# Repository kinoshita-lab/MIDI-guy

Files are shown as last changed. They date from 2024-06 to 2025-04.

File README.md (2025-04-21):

# MIDI Guy by Kinoshita Laboratory

[japanese version](./README.ja.md)

MIDI Guy is a sound module with SAM2695, a single chip General MIDI(GM) synthesizer.
It can generate GM's 127 sound programs such as "Acoustic Grand Piano", "Trumpet", etc.

You can also use effects and EQs. Please refer to the SAM2695's datasheet for details.
<https://www.dream.fr/pdf/Serie2000/SAM_Datasheets/SAM2695.pdf>

# Selling PCBA at tindie.com!
Please visit: <https://www.tindie.com/products/kinoshitalab/midi-guy-rev-21-kit/>

## What's new for Revision 2.1

- USB Power input is replaced from micro USB to USB Type-C
- PCB Dimension modification: fit for Frisk case
- Support both TRS MIDI type A and B
- Add UART In terminal for the convinience using with microcontroller

## Kit contents

- Pre-assembled circuit board
- 2 pcs. of 3.5mm TRS Jack
- 1 pc. of DIN <-> TRS(Type A) Conversion Cable

## What you will need

- USB C Cable
- Power source for USB, such as power adapter or PC
- MIDI cable
- MIDI Output Device e.g. MIDI Keyboard, PC with MIDI Interface

## How to assemble

Solder the included TRS Jacks to the places shown below.

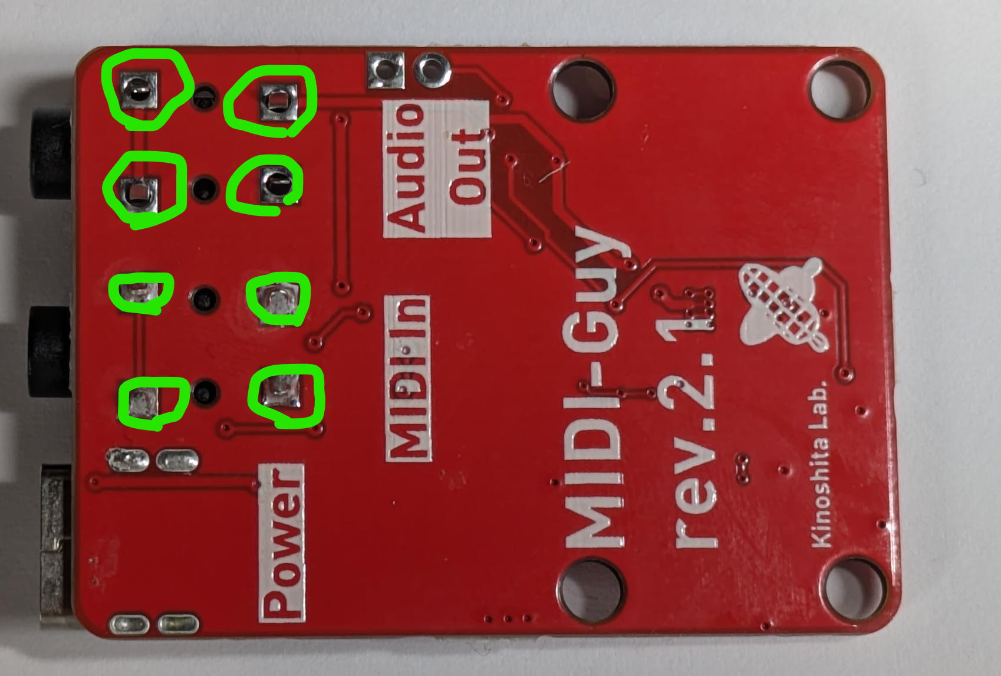
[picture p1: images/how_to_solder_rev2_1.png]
how to solder
  

## Usage

- Power: Connect the power source from USB
- MIDI In: Connect a MIDI message source(e.g. MIDI Keyboard, MIDI Interface connected to a PC)
- Audio Out: Outputs stereo sound, you can connect headphones directly.

## Schematics, design data, questions

<https://github.com/kinoshita-lab/MIDI-guy>

## Case Design
STL file made by @maks. Thank you!!
https://www.printables.com/model/1151667-case-for-a-midi-guy-pcb

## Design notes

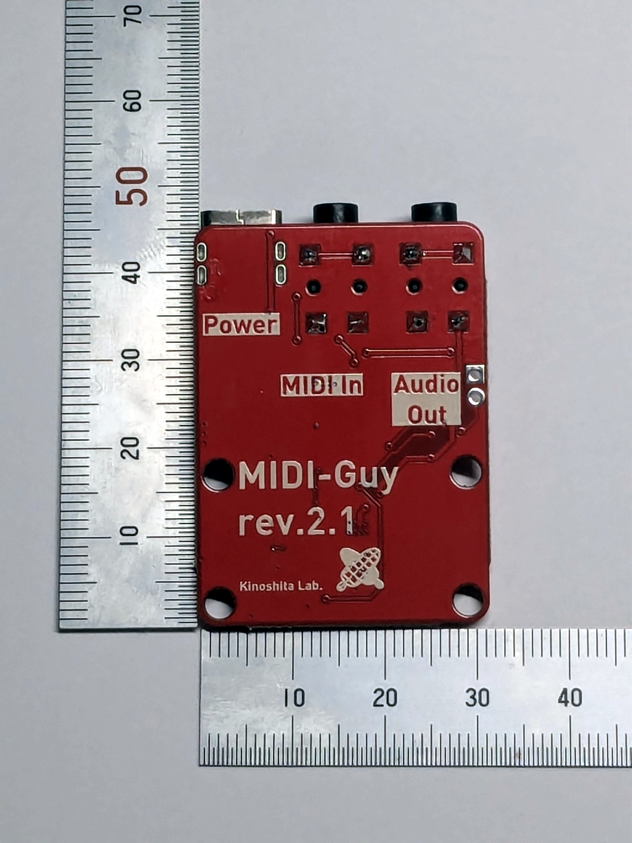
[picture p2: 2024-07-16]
pic_bottom.jpg

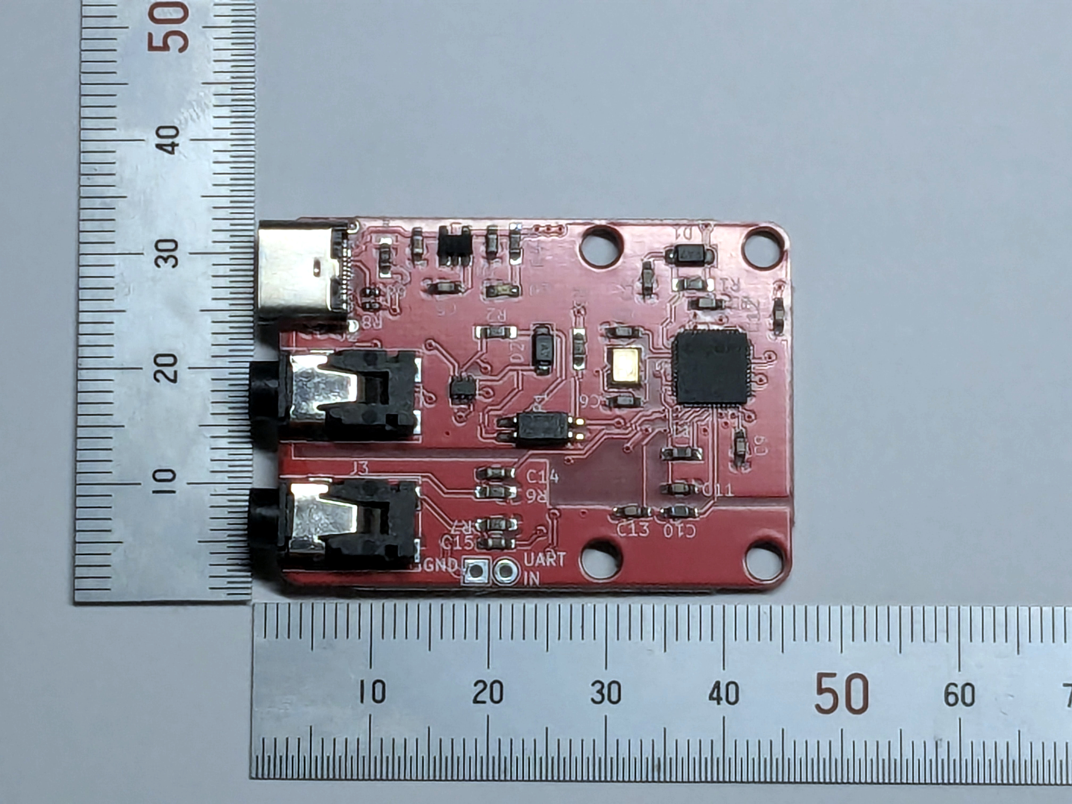
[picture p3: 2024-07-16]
pic_top.jpg

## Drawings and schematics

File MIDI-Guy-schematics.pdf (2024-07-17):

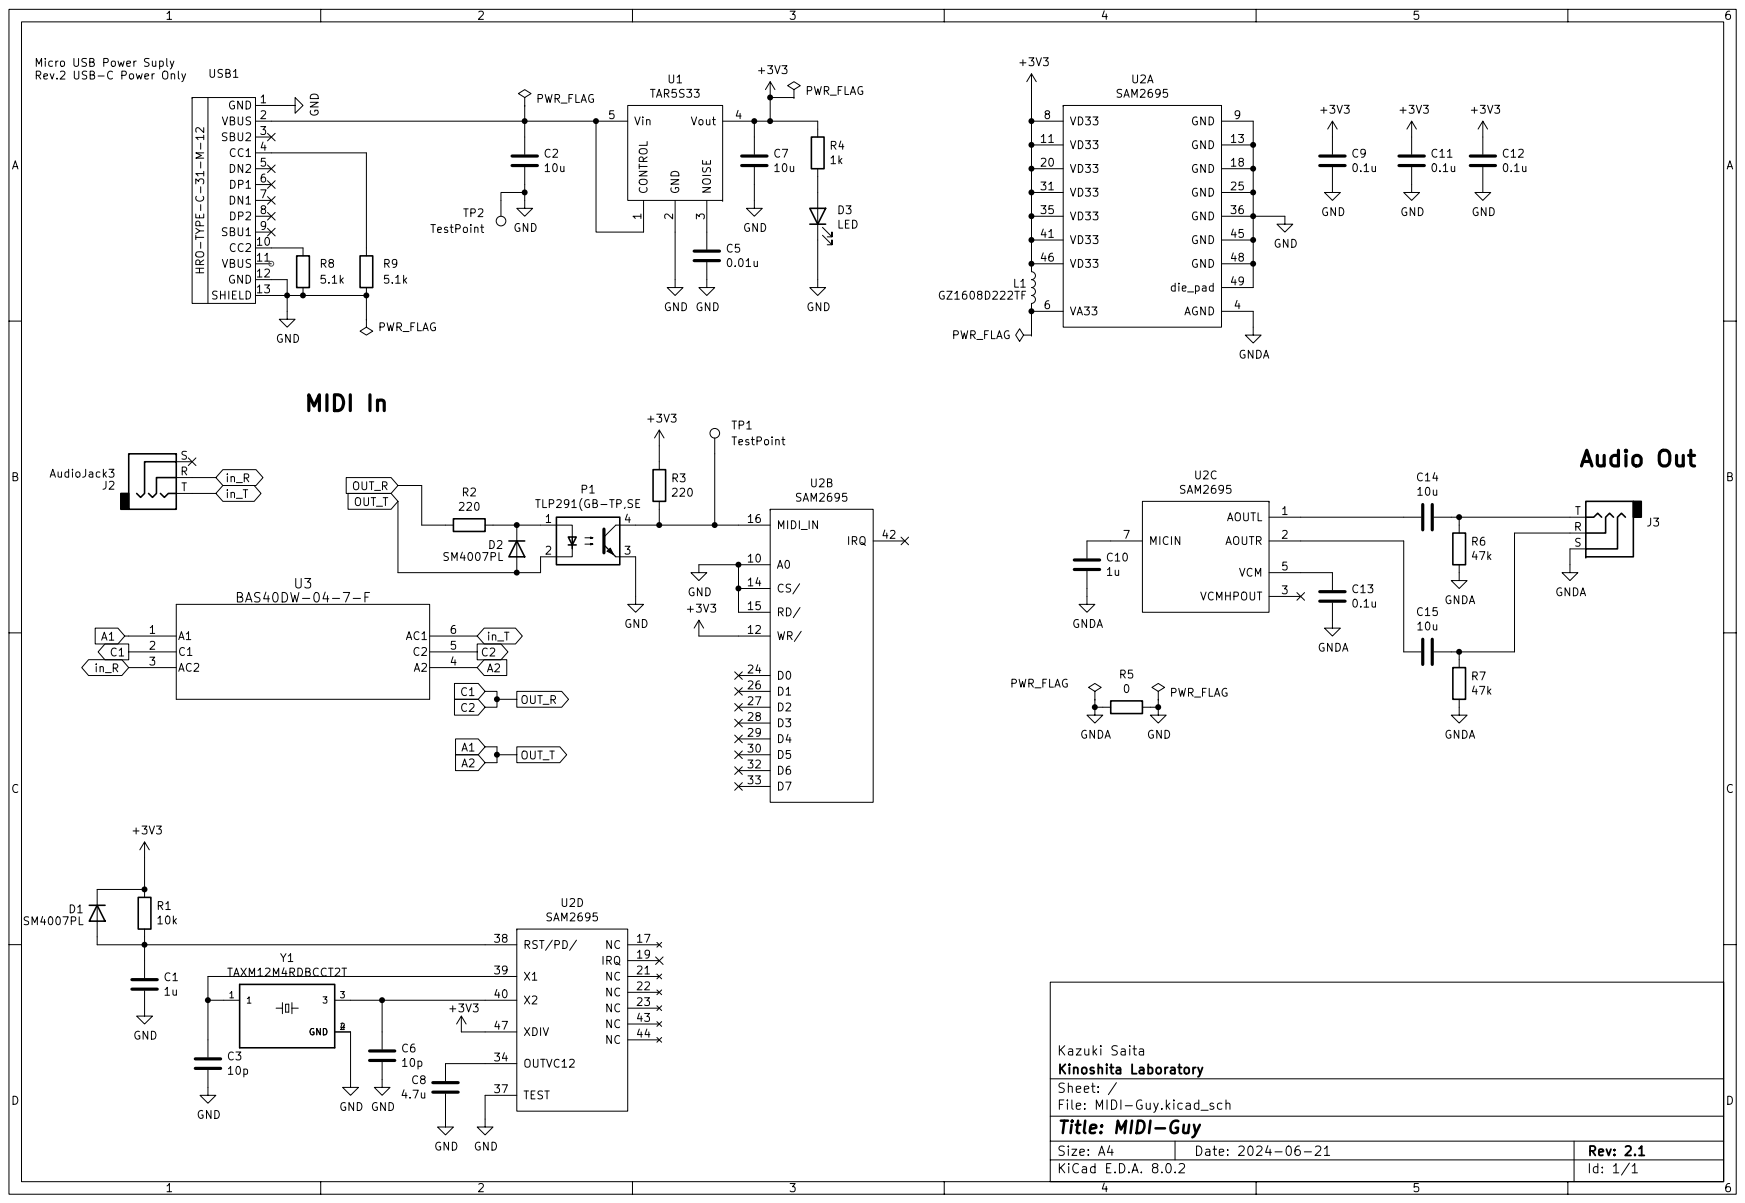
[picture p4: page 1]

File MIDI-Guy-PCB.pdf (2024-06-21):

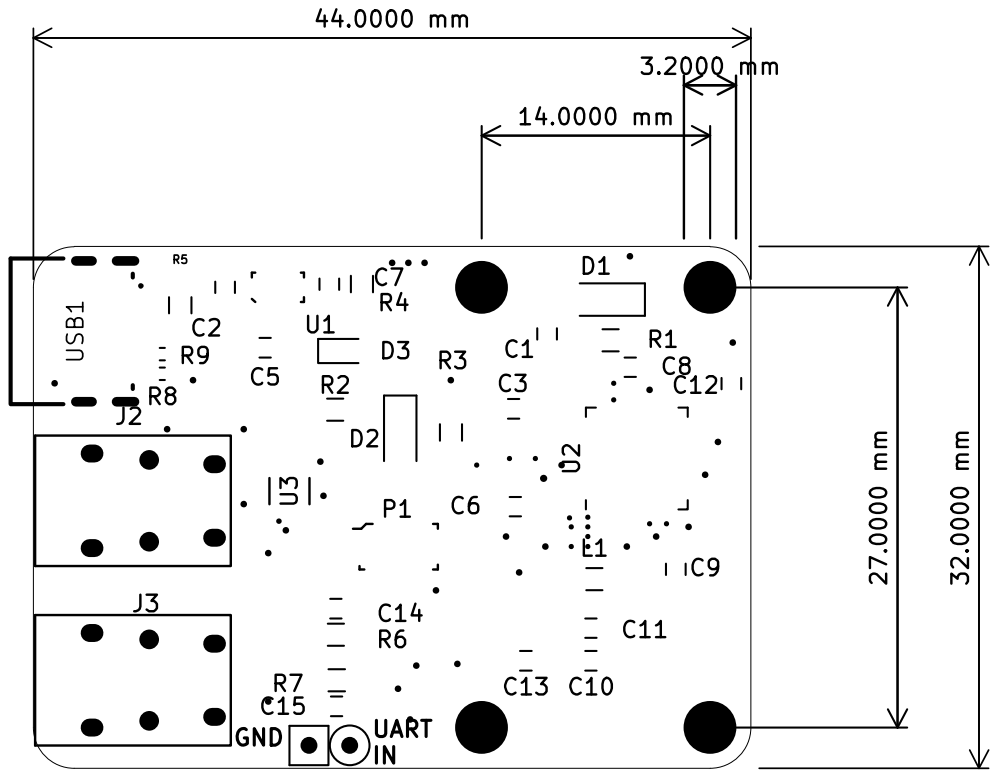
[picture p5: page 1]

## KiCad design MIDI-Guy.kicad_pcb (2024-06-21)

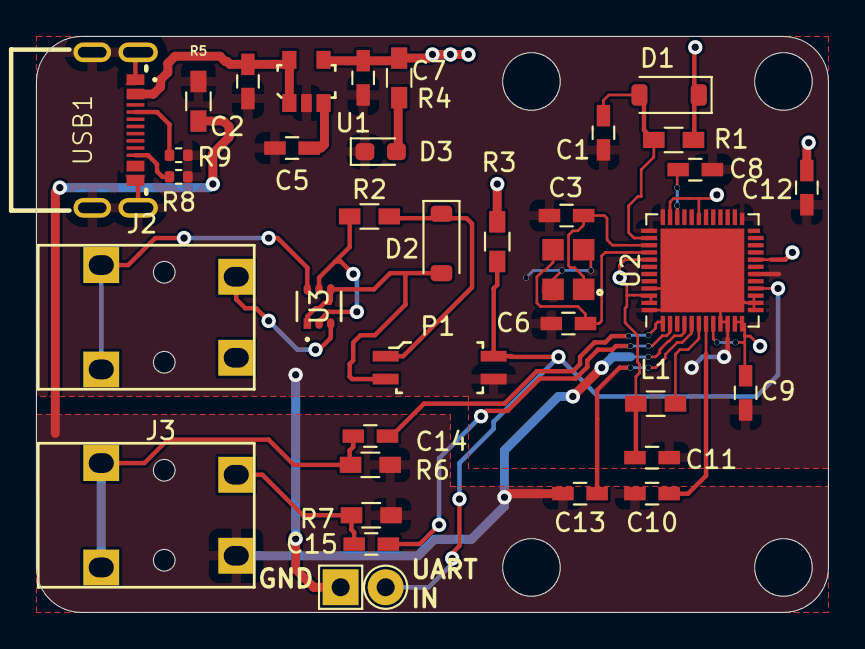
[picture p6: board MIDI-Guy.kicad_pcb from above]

Board: 2 copper layers, 44.0 x 32.0 mm, 39 parts (0 on the bottom side), 25 nets.

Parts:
C1, C10: 1u; C_0603_HandSoldering
C2, C7, C14, C15: 10u; C_0603_HandSoldering
C3, C6: 10p; C_0603_HandSoldering
C5: 0.01u; C_0603_HandSoldering
C8: 4.7u; C_0603_HandSoldering
C9, C11, C12, C13: 0.1u; C_0603_HandSoldering
D1, D2: SM4007PL; D_SOD-123
D3: LED; LED_0603_1608Metric_Pad1.05x0.95mm_HandSolder
J2, J3: AudioJack3; 3.5mm_Stereo_TRS_PJ-3210-4A_and_ST-005-G
L1: GZ1608D222TF; L_0603_HandSoldering
P1: TLP291(GB-TP,SE; TLP291
R1: 10k; R_0603_HandSoldering
R2, R3: 220; R_0603_HandSoldering
R4: 1k; R_0603_HandSoldering
R5: 0; R_0603_HandSoldering
R6, R7: 47k; R_0603_HandSoldering
R8, R9: 5.1k; R_0402_1005Metric
REFe: MountingHole_3.2mm_M3_DIN965
REFe#2: MountingHole_3.2mm_M3_DIN965
TP1: TestPoint; TestPoint_THTPad_D2.0mm_Drill1.0mm
TP2: TestPoint; TestPoint_THTPad_2.0x2.0mm_Drill1.0mm
U1: TAR5S33; TAR5S33_Akizuki_Toshiba_SSOP5
U2: SAM2695; SAM2695_QFN-48-6x6mm_Pitch0.4mm
U3: BAS40DW-04-7-F; SOT-363_DIO
USB1: HRO TYPE-C-31-M-08A
Y1: TAXM12M4RDBCCT2T; OSCSC320X250X100N

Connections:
+3V3: C7.1, C9.1, C11.1, C12.1, D1.1 (K), L1.1, R1.1, R3.2, R4.1, U1.4 (Vout), U2.8 (VD33), U2.11 (VD33), U2.12 (WR/), U2.20 (VD33), U2.31 (VD33), U2.35 (VD33), U2.41 (VD33), U2.46 (VD33), U2.47 (XDIV)
A1: D2.2 (A), P1.2, U3.1 (A1), U3.4 (A2)
C1: R2.2, U3.2 (C1), U3.5 (C2)
GND: C1.2, C2.2, C3.2, C5.2, C6.2, C7.2, C8.2, C9.2, C11.2, C12.2, D3.1 (K), P1.3, R5.2, R8.1, R9.2, TP2.1, U1.2 (GND), U2.9 (GND), U2.10 (A0), U2.13 (GND), U2.14 (CS/), U2.15 (RD/), U2.18 (GND), U2.25 (GND), U2.36 (GND), U2.37 (TEST), U2.45 (GND), U2.48 (GND), U2.49 (die_pad), USB1.1 (GND), USB1.12 (GND), USB1.13 (SHIELD), Y1.2 (GND), Y1.4 (GND)
GNDA: C10.2, C13.1, J3.S, R5.1, R6.1, R7.1, U2.4 (AGND)
unnamed: C14.1, J3.T, R6.2
unnamed: C15.1, J3.R, R7.2
unnamed: C1.1, D1.2 (A), R1.2, U2.38 (RST/PD/)
unnamed: D2.1 (K), P1.1, R2.1
unnamed: D3.2 (A), R4.2
unnamed: C2.1, U1.1 (CONTROL), U1.5 (Vin), USB1.2 (VBUS)
unnamed: C5.1, U1.3 (NOISE)
unnamed: L1.2, U2.6 (VA33)
unnamed: P1.4, R3.1, TP1.1, U2.16 (MIDI_IN)
unnamed: C14.2, U2.1 (AOUTL)
unnamed: C15.2, U2.2 (AOUTR)
unnamed: C10.1, U2.7 (MICIN)
unnamed: C13.2, U2.5 (VCM)
unnamed: C8.1, U2.34 (OUTVC12)
unnamed: C3.1, U2.39 (X1), Y1.1
unnamed: C6.1, U2.40 (X2), Y1.3
unnamed: R9.1, USB1.4 (CC1)
unnamed: R8.2, USB1.10 (CC2)
in_R: J2.R, U3.3 (AC2)
in_T: J2.T, U3.6 (AC1)

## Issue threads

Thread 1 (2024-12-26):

Is a case design available?

maks, 2024-12-26:
Hi, thank you for making such a wonderful little PCB with the sam2695 MIDI module.
I noticed in the readme you have:

>fit for Frisk case

so I wanted to ask if there is already a 3d print case design?
If there isn't I might have a go at designing a basic one myself.

maks, 2025-01-16:
Hi, I ended up making a simple case for your wonderful little midi module in case anyone else might find it useful I [published the 3d print files](https://www.printables.com/model/1151667-case-for-a-midi-guy-pcb).

kinoshita-lab, 2025-01-17:
Hello, thank you for your design data.
I added URL for both README and README.ja.

Closed 2025-01-17.

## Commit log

2019-08-03 for MFT 2019
    [MIDI-Guy.kicad_pcb, MIDI-Guy.sch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]
2019-10-04 add PCB Dimension info
    [MIDI-Guy.kicad_pcb]
2020-02-08 move cap to avoid conflict on panellizing
    [MIDI-Guy-B_Cu.gbl, MIDI-Guy-B_Mask.gbs, MIDI-Guy-B_Paste.gbp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]
2021-05-19 - Change R3 value from 470 to 220, due to receiving failure according to the transfer current spec of TLP291 - Remove panelized pcb and gerber data, since they are not maintained
    [MIDI-Guy.kicad_pcb, MIDI-Guy.sch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]
2024-06-21 Update to revision 2.1 with tidying unused, obsolete files
    [MIDI-Guy-B_Cu.gbl, MIDI-Guy-B_Mask.gbs, MIDI-Guy-B_Paste.gbp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]
2024-07-16 add images how to assemble 2.1
2024-07-17 replace wrong schematics
